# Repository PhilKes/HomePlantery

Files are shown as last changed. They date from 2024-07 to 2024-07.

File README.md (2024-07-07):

# HomePlantery

[Plantwatery](https://github.com/Lumics/Plantwatery) but with ESPHome (based on [ESPlanty](https://community.home-assistant.io/t/esplanty-self-watering-solar-powered-plant-no-plumbing-no-powerpoints-irrigation-deep-sleep-battery/464263))

# Hardware
- [ESP32 WSROOM](https://www.amazon.com/ESP-WROOM-32-Development-Microcontroller-Integrated-Compatible/dp/B08D5ZD528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)
- [Capacity Soil Moisture Sensor](https://de.aliexpress.com/item/32892951369.html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)(2 slots available)
- [1 Channel 5V Relay Board](https://de.aliexpress.com/item/1005005626475953.html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)
- [MCP1700 3.3v Voltage Regulator](https://www.aliexpress.com/item/1005001608339185.html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)
- [5V 1.2W (at least 0.5W) Solar Panel](https://de.aliexpress.com/item/1005004198199771.html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)
- [5V 2.4W Decdeal Water Pump](https://www.amazon.de/dp/B07B49VKJH?psc=1&ref=ppx_yo2ov_dt_b_product_details)
- [Pneumatic Tube 6mm](https://www.aliexpress.com/item/4000859747207.html?spm=a2g0o.order_list.order_list_main.11.bb595c5f6tNArW)
- [Pneumatic Tube T Connector 6mm outer diameter](https://de.aliexpress.com/item/1005003985521367.html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)
- [Pneumatic Tube End Connector 6mm outer diameter](https://www.aliexpress.com/item/4001338085412.html?spm=a2g0o.order_list.order_list_main.12.bb595c5f6tNArW)
- Slide Switch
- Water Canister (e.g. [Plastic Box 12 litres](https://www.hornbach.de/p/kunststoffbox-dirk-xs-12-l-255x170x370-mm/8493487/))
- M3 (4-9mm long) Screws for mounting

__Note: My Hardware setup in theory allows to connect 2 moisture sensors and 2 water pumps, but only 1 each is used as of now.__

## Schematic
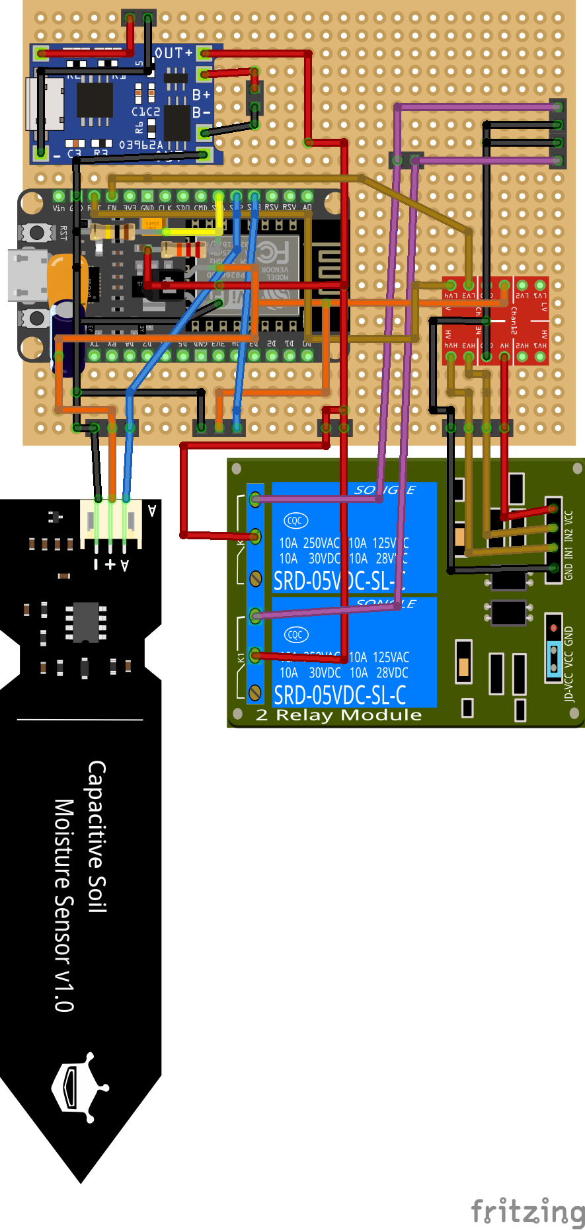
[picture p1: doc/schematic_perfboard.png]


[Fritzing Schematic](./doc/schematic_perfboard.fzz)

# Software

## Requirements
- [Home Assistant](https://www.home-assistant.io/)
- [ESPHome integration](https://www.home-assistant.io/integrations/esphome/)
- Create [Input Boolean Helper integration](https://www.home-assistant.io/integrations/input_boolean/) with id `input_boolean.ota_update_available`

## Code
[plant_watering_control.yaml](./homeassistant/plant_watering_control.yaml):

1. Checks if there are OTA Updates available (toggle in HA), if there are updates, prevent deep sleep
2. Reset sensors and take measurements (median with sliding window, notification with sensor values)
3. Start watering if moisture is below threshold (notification for water pump start and stop action)
4. Re-measure moisture change (notification if moisture didn't rise as expected)
5. Enter deep-sleep until configured time of day (20:00)

# 3D Printed Parts
All parts should be printed with ASA or PETG, because PLA can start to deteriorate and deform in warm and wet weather conditions.

## Electronics Case
- [Bottom Case](./3dprint/case/electronics/electronics_case_bottom.stl) with holes for ESP32 USB-C, TP4056 micro USB, Slide Switch, Cable holes
- [Top Case](./3dprint/case/electronics/electronics_case_top.stl) with mounting screw holes

## Solar Panel Case
- [Solar Panel Case](./3dprint/case/solar_panel/solar_panel_case_base.stl) with M3 screw mounting hole
- [Solar Panel Clamp](https://www.thingiverse.com/thing:6668830) as alternative to mounting via M3 screw

## Watering System parts
See [/3dprint/watering_system](./3dprint/watering_system) for all available parts

- Sprinkler Connector
- Sprinkler tops with different holes
- Sprinkler holders (vertical/horizontal)
- Tube 5-Way Splitter (8mm to 4mm inner diameter)
- [Tube Clamp](./3dprint/watering_system/water_canister/tube_ring_clamp.stl) to fix 8mm tube on Water Pump

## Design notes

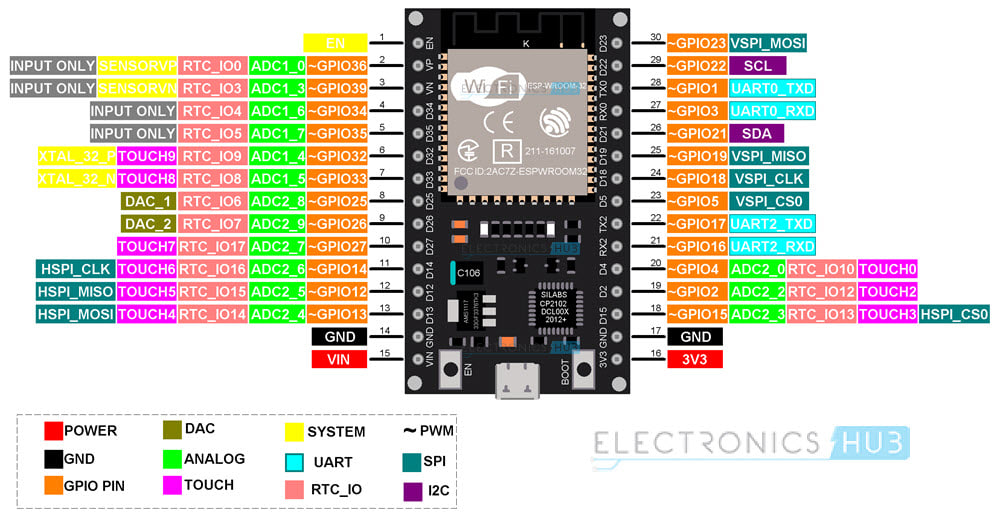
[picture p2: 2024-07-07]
doc/esp32_wsroom_pinout.jpg

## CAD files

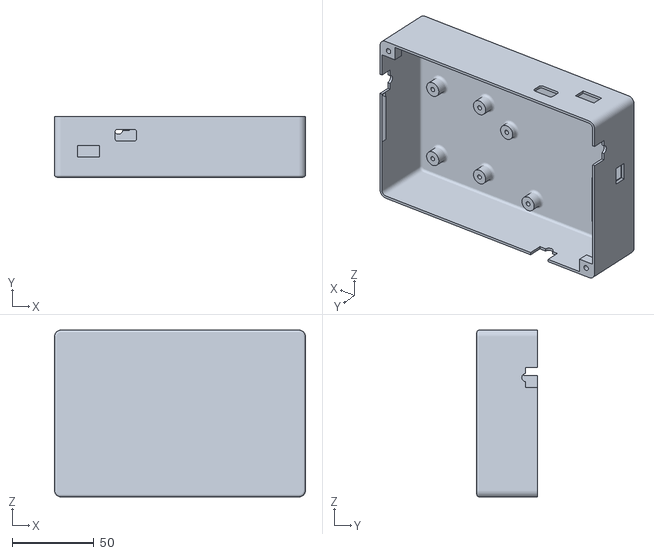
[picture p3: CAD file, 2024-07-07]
3dprint/case/electronics/electronics_case_bottom.stl
153.5 x 37.0 x 102.0

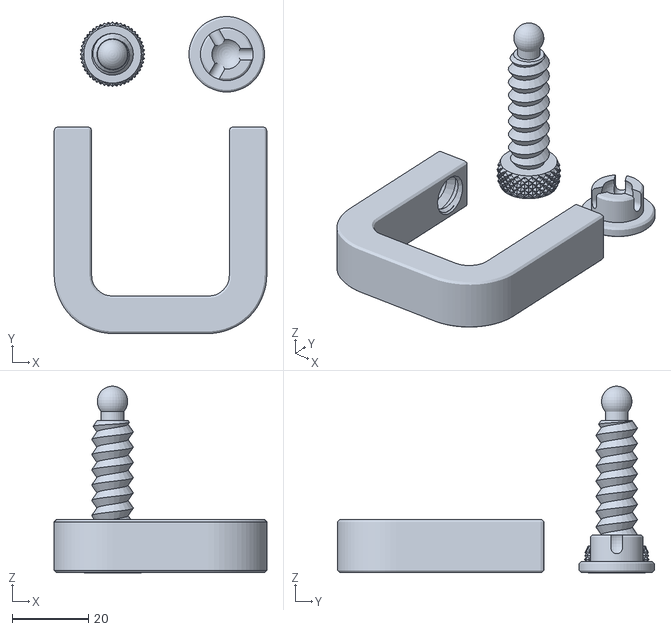
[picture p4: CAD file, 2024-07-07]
3dprint/case/solar_panel/solar_panel_clamp.stl
55.8 x 83.2 x 49.0

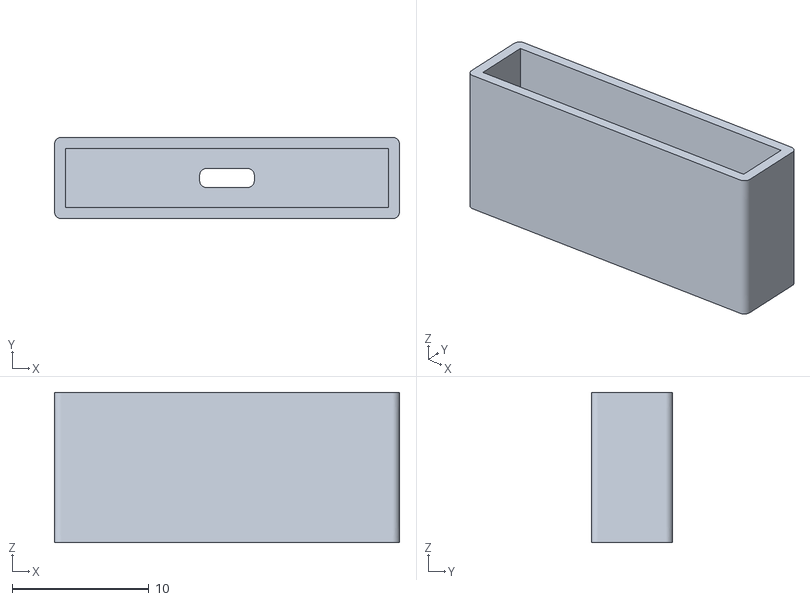
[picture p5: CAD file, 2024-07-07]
3dprint/moisture_sensor/moisture_sensor_case_top.stl
25.3 x 5.95 x 11.0

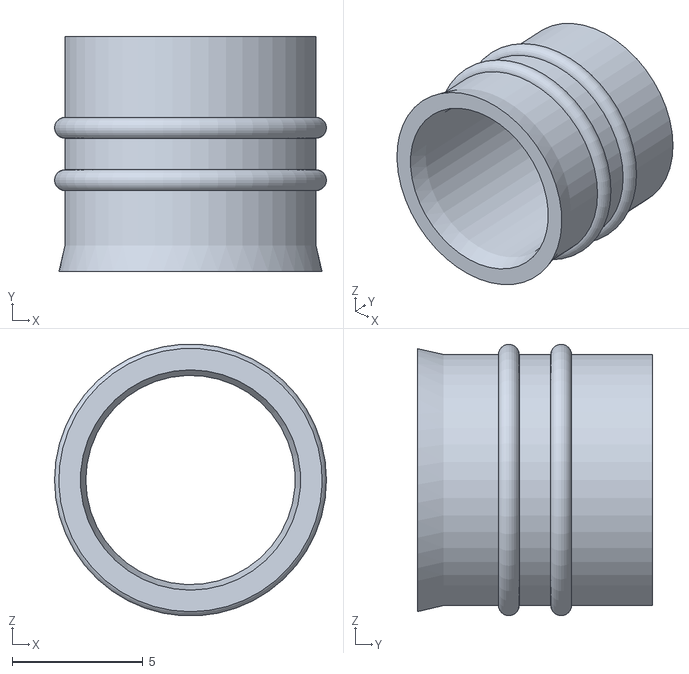
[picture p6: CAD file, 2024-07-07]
3dprint/watering_system/splitter_big_test.stl
10.4 x 9.00 x 10.4

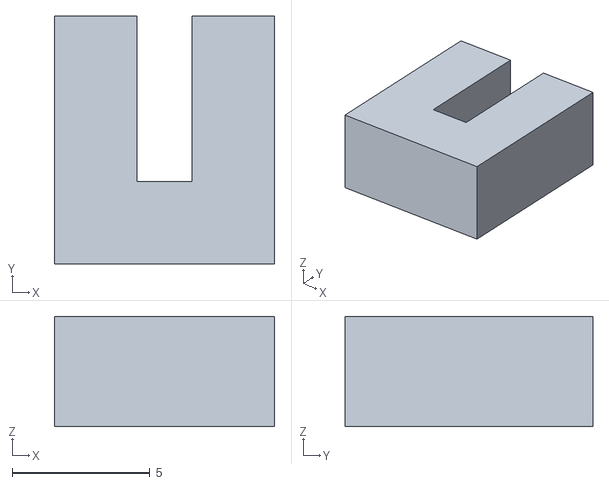
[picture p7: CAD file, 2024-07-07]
3dprint/watering_system/water_canister/water_canister_lid_holder_top_test.stl
8.00 x 9.00 x 4.00

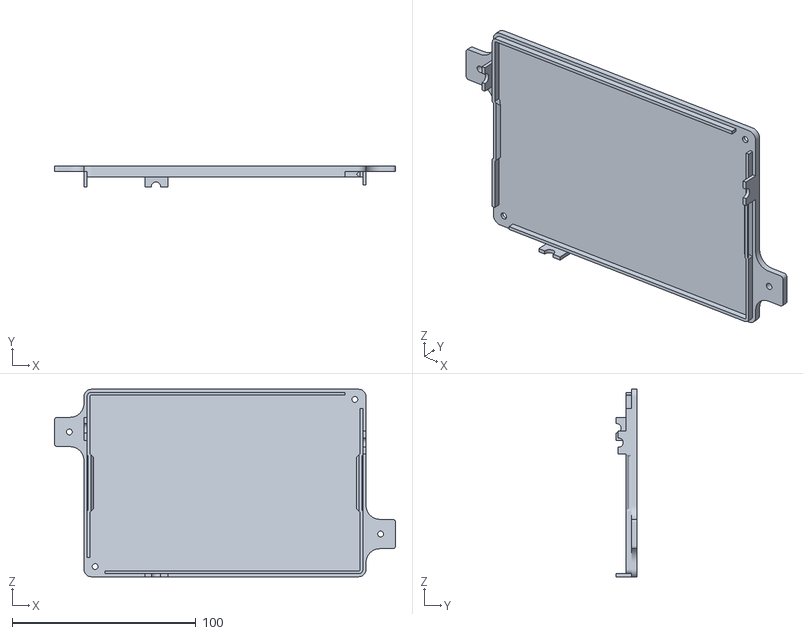
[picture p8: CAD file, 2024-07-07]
3dprint/case/electronics/electronics_case_top.stl
185.5 x 11.5 x 102.0

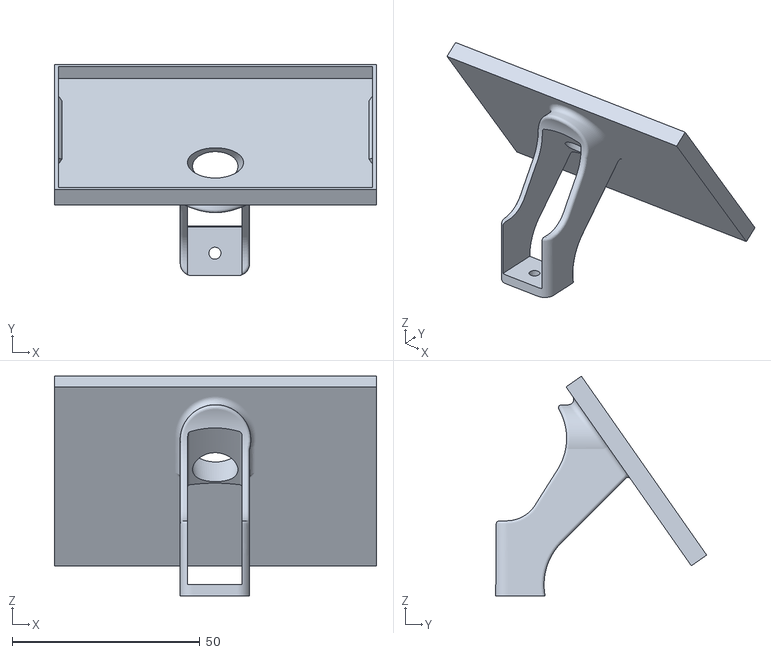
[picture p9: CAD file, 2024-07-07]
3dprint/case/solar_panel/solar_panel_case_base.stl
85.8 x 56.3 x 58.5

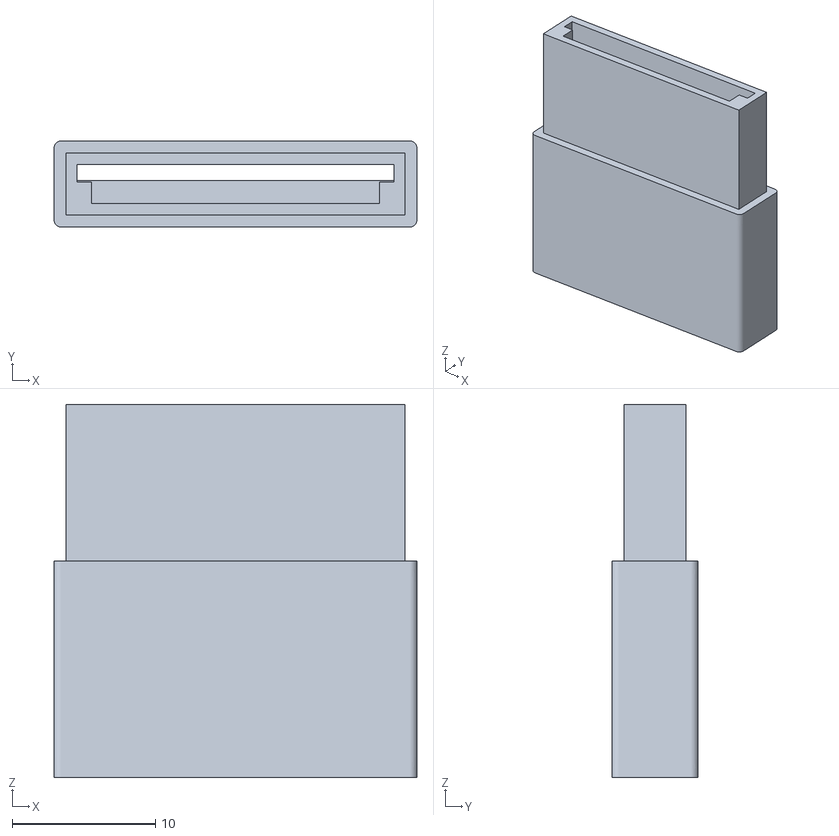
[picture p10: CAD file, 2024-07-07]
3dprint/moisture_sensor/moisture_sensor_case_bottom.stl
25.3 x 6.00 x 26.0

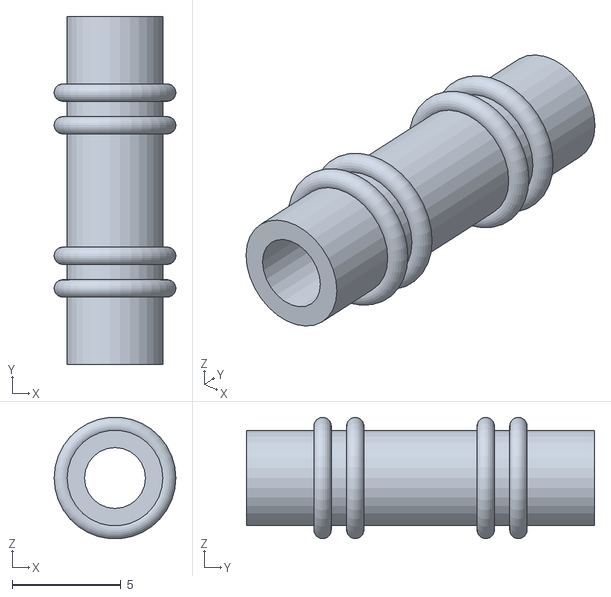
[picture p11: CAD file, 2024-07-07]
3dprint/watering_system/4mm_Tube_extension.stl
5.60 x 16.0 x 5.58

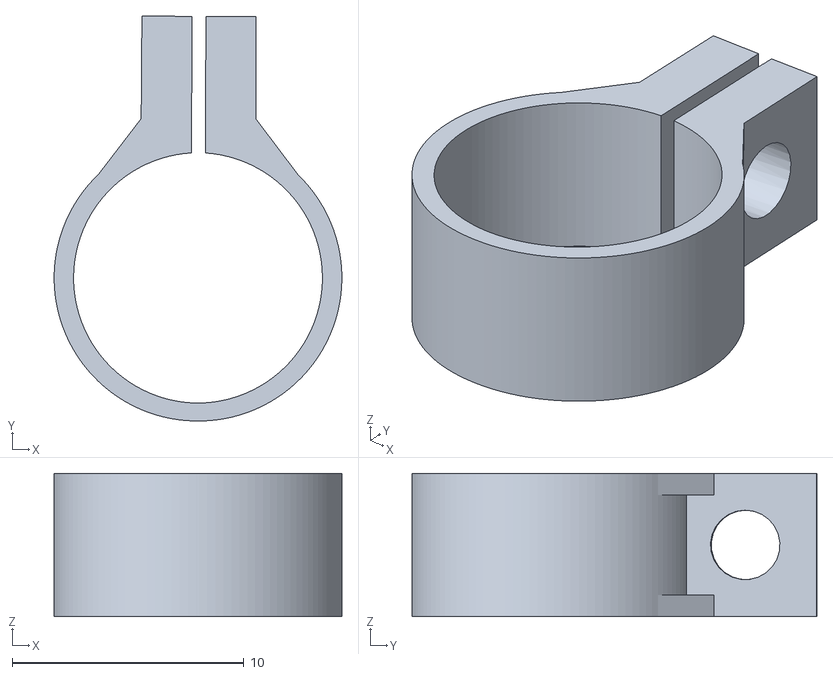
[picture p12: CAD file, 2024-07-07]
3dprint/watering_system/water_canister/tube_ring_clamp.stl
12.4 x 17.5 x 6.18

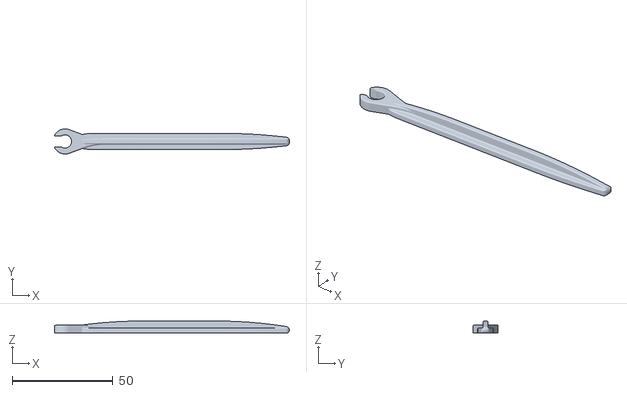
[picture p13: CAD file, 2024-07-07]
3dprint/watering_system/4mm_Sprinkler_holder_horizontal.stl
116.7 x 12.5 x 6.00

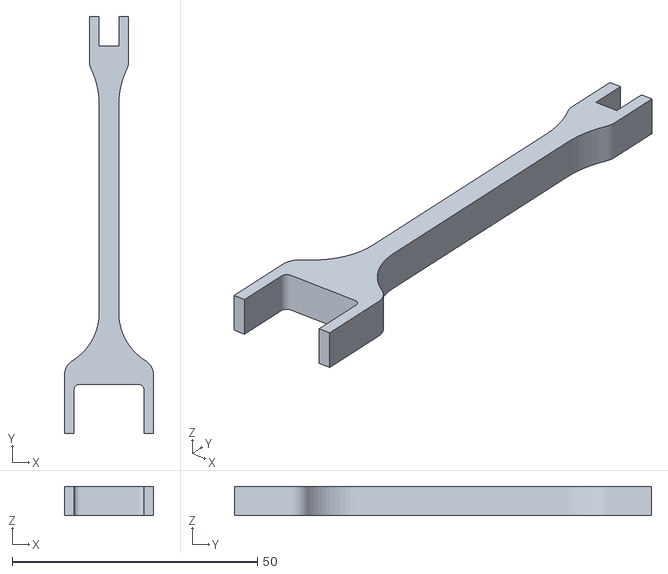
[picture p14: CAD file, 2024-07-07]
3dprint/watering_system/water_canister/water_canister_lid_holder.stl
18.2 x 85.0 x 6.00

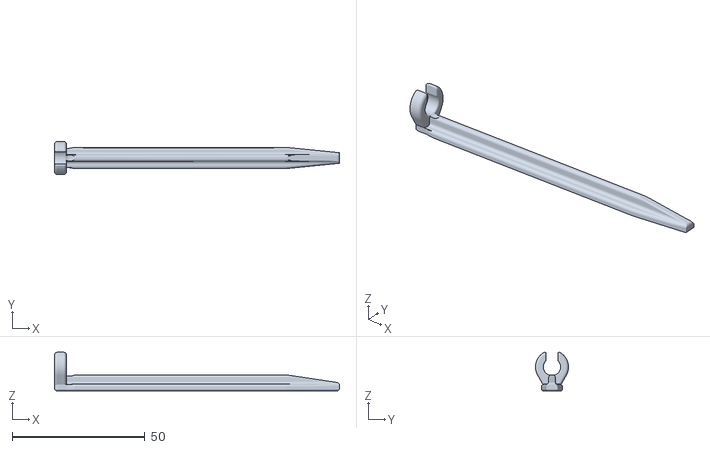
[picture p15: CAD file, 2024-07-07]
3dprint/watering_system/4mm_Sprinkler_holder_vertical.stl
107.5 x 12.5 x 14.5

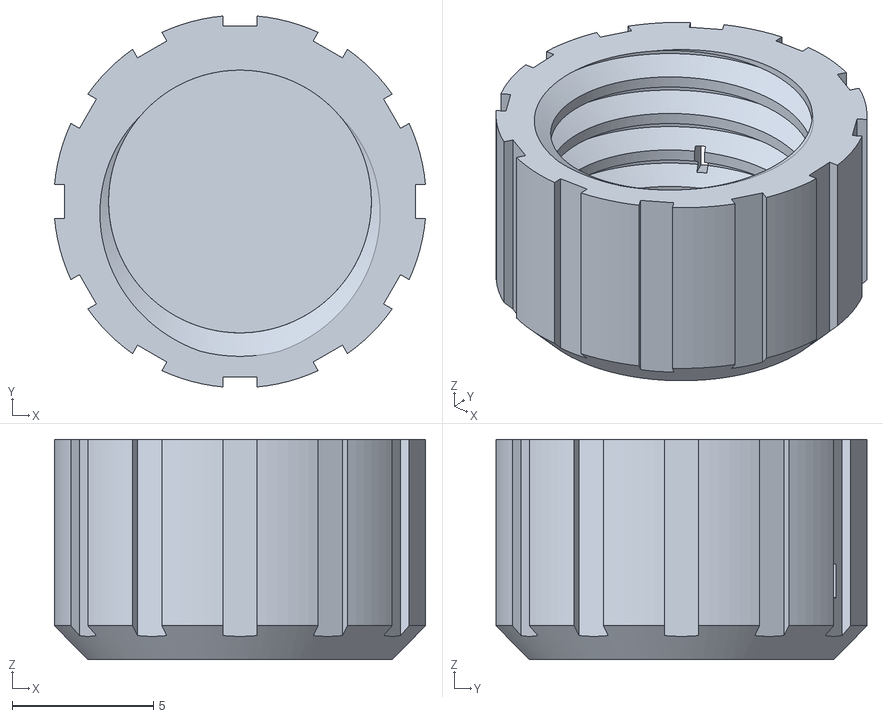
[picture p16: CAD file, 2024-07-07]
3dprint/watering_system/4mm_Sprinkler_Top_vertical_half.stl
13.1 x 13.1 x 7.80

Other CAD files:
3dprint/watering_system/4mm_Sprinkler_Top_vertical_4way.stl
3dprint/watering_system/4mm_Sprinkler_Top_vertical_2way_opposite_big.stl
3dprint/watering_system/4mm_Sprinkler_Top_horizontal_front_only.stl
3dprint/watering_system/8-to-4mm-7-way-Splitter.stl
3dprint/case/electronics/electronics_case.f3d
3dprint/case/solar_panel/solar_panel_case.f3d
3dprint/watering_system/4mm_Sprinkler_Top_Big.stl
3dprint/watering_system/4mm_Sprinkler_Top_horizontal.stl
3dprint/watering_system/4mm_Sprinkler_Top_vertical.stl
3dprint/watering_system/4mm_Sprinkler_Top_vertical_2way_opposite.stl
3dprint/watering_system/4mm_Sprinkler_Top_vertical_opposite.stl
3dprint/watering_system/4mm_Sprinkler_bottom_small.stl
3dprint/watering_system/4mm_Tube_3_way_connector.stl
3dprint/watering_system/8-to-4mm-5-way-Splitter.stl
3dprint/watering_system/splitter_small_test.stl

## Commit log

2024-07-07 doc: add electronics schematic
    [schematic_perfboard.fzz]
2024-07-07 feat: add 3d-print models and Fusion360 designs
    [4mm_Sprinkler_Top_Big.stl, 4mm_Sprinkler_Top_horizontal.stl, 4mm_Sprinkler_Top_horizontal_front_only.stl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]
